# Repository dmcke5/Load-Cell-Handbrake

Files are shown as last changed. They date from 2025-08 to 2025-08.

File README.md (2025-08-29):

# CNCDan - Load Cell Handbrake
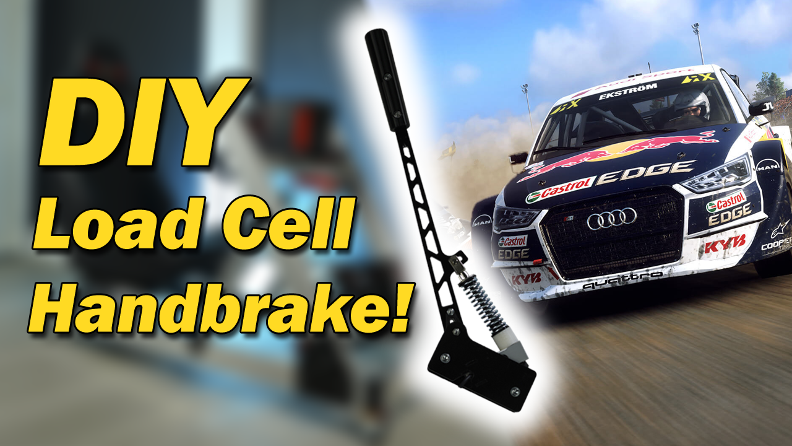
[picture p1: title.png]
Load Cell Handbrake


A load cell based handbrake design that's compatible with all of my other DIY Sim Racing projects.

[Project Video Link](https://youtu.be/xzpE0UGo8F0)

There are two different versions of the handbrake design, "Printed" and "Laser cut".
The laser cut version does still have some printed components, but the printed version does not require any laser cut parts!

Both versions are based around the same NA151 200kg Load cell - https://www.aliexpress.com/item/1005005510555008.html

And the INA333 amplifier board - https://www.aliexpress.com/item/1005007130064459.html

The files are split up into folders for each version. I've supplied STEP files for the parts that need to be laser cut, and STL files for any of the printed components! Each file has an x number at the end to denote how many copies of that part need to be made.

The "TPE Brake Bushing" file should be printed in flexible filament and without external walls to allow the print to compress nicely. I printed mine at 75% infill but you can tune that number up and down to vary the hardness.

Code to support both versions of the handbrake is now included in the [H-Shifter](https://github.com/dmcke5/H-Shifter) software. If you don't already have the shifter, this code can still be used without any modifications. Here is a wiring diagram to connect the Load cell to the INA333 board and then your Arduino. Make sure you include the jumpers across the potentiometer and between VREF and GND:

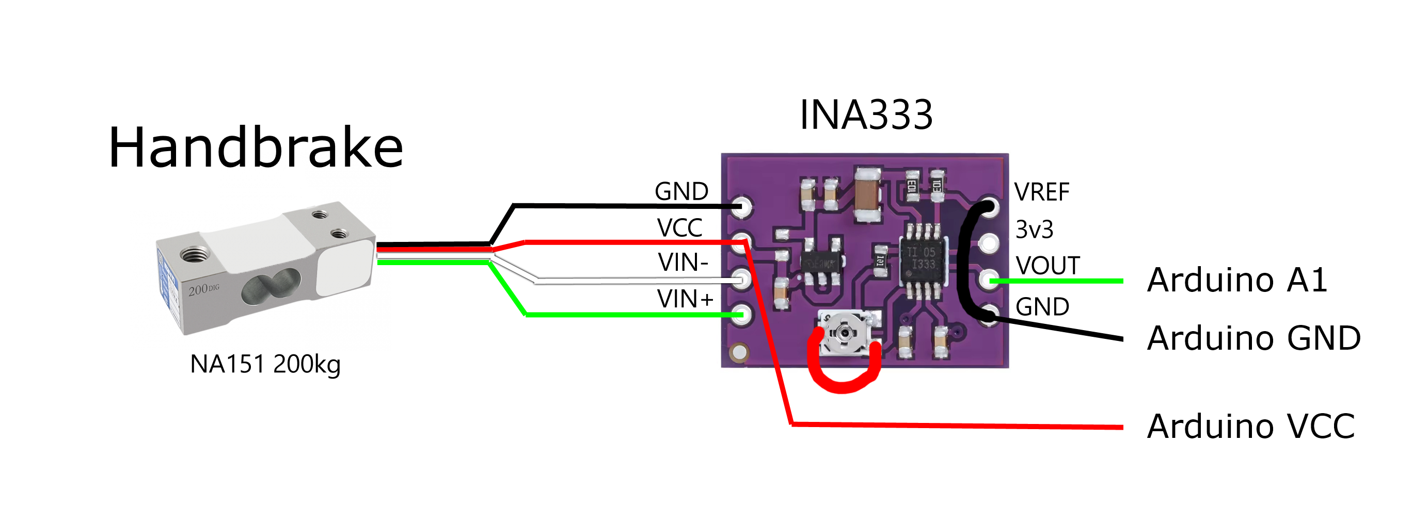
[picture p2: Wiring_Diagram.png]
Wiring Diagram


You'll also need the following items:

1x M6 Clevis - https://www.aliexpress.com/item/1005001383989512.html

1x M6x25 Washer - https://www.aliexpress.com/item/1005008724152831.html

22mm Diameter 70mm Long 3mm Wire Spring - https://www.aliexpress.com/item/1005007839215181.html

1x M6x140mm - https://www.aliexpress.com/item/1005008952546224.html

2x 625 Bearings - https://www.aliexpress.com/item/1005006600483688.html

1x 6x12x8 Retaining Collar - https://www.aliexpress.com/item/1005004975920947.html

3x M5x50 (45's would be acceptable for the Laser cut version) - https://www.aliexpress.com/item/32965712827.html

3x M5 Nyloc Nut - https://www.aliexpress.com/item/1005008280044118.html

#### Extra parts for Laser Cut Version Only

2x M6 Nyloc Nut - https://www.aliexpress.com/item/1005008280044118.html

2x M6x20 - https://www.aliexpress.com/item/32965712827.html

2x M5x35 - https://www.aliexpress.com/item/32965712827.html

#### Extra parts for Printed Version Only

2x M5x60 - https://www.aliexpress.com/item/32965712827.html

1x 10mm Shaft 350mm Long - https://www.aliexpress.com/item/1005006293171727.html

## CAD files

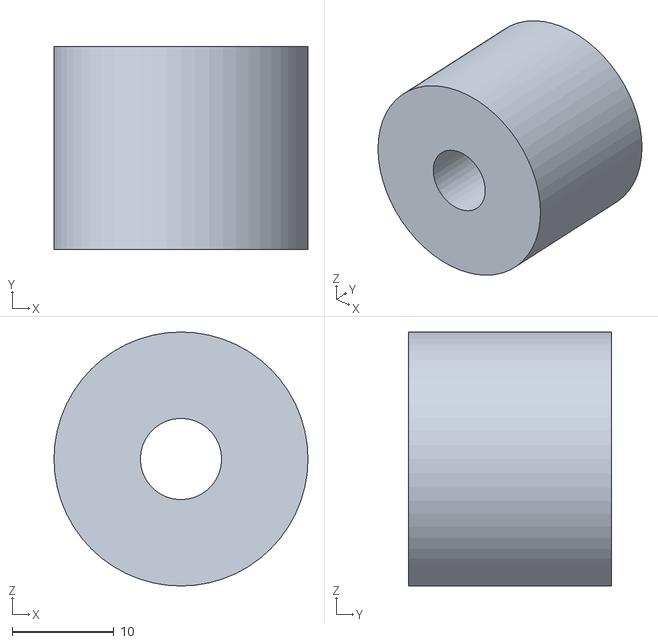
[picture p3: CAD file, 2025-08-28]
3D Files/Laser Cut Version/TPE Brake Bushing x1.STL
25.0 x 20.0 x 25.0

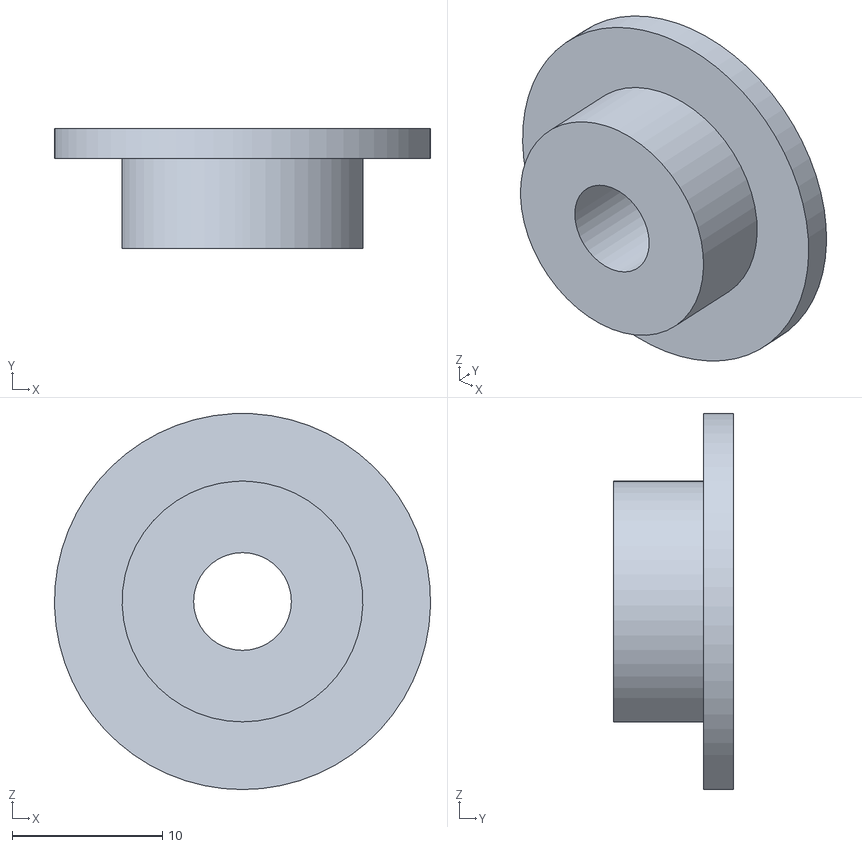
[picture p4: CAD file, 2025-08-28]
3D Files/Laser Cut Version/Spring Seat x2.STL
25.0 x 8.00 x 25.0

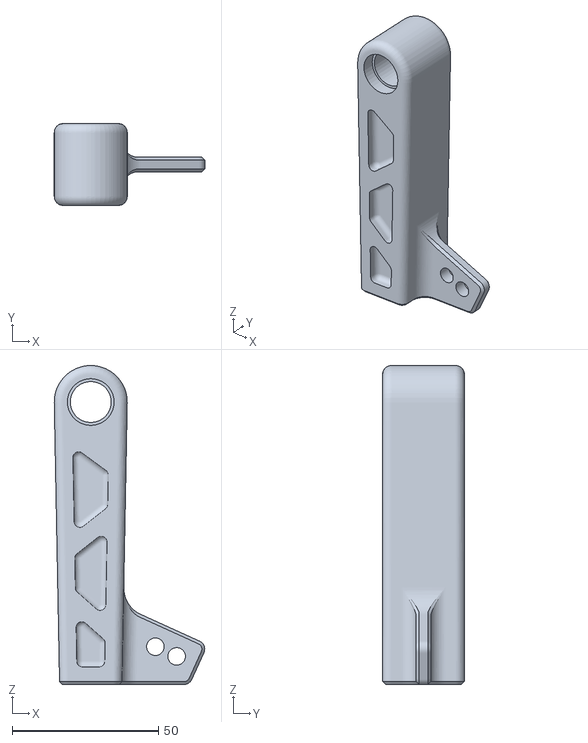
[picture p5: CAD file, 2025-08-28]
3D Files/Printed Version/Printed - Handbrake Arm Base x1.STL
51.5 x 28.0 x 109.2

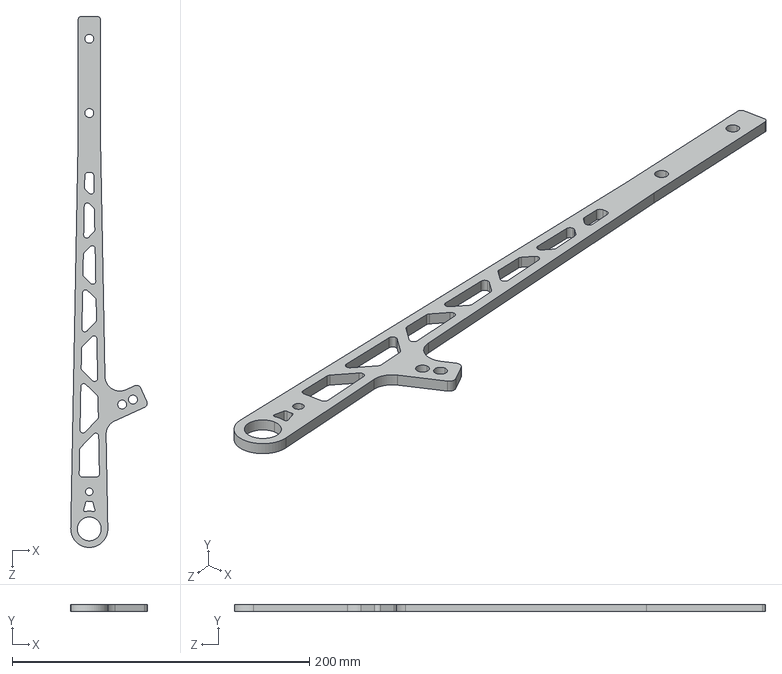
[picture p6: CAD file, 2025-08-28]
3D Files/Laser Cut Version/Laser - Handbrake Arm x1.STEP
51.5 x 5.00 x 357.5 mm

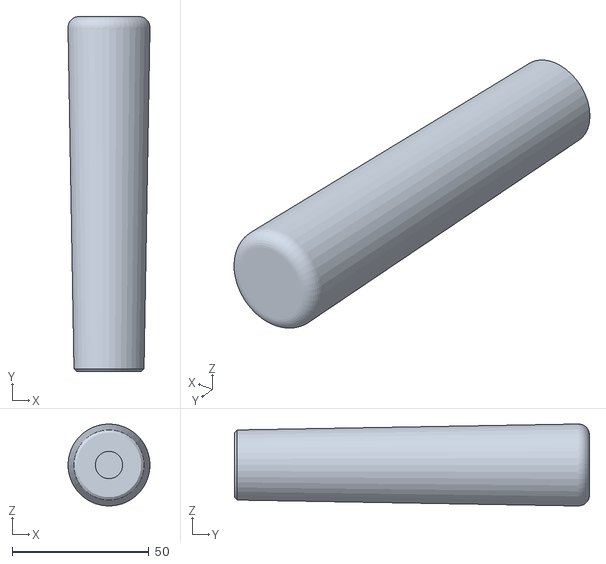
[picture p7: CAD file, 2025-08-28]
3D Files/Printed Version/Printed - Handbrake Arm Handle x1.STL
30.0 x 130.0 x 30.0

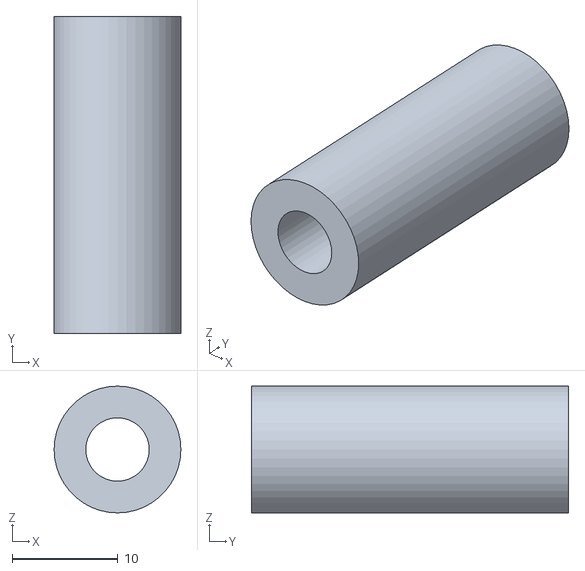
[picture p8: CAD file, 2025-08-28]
3D Files/Laser Cut Version/Laser - Handbrake Plate Spacer x2.STL
12.0 x 30.0 x 12.0

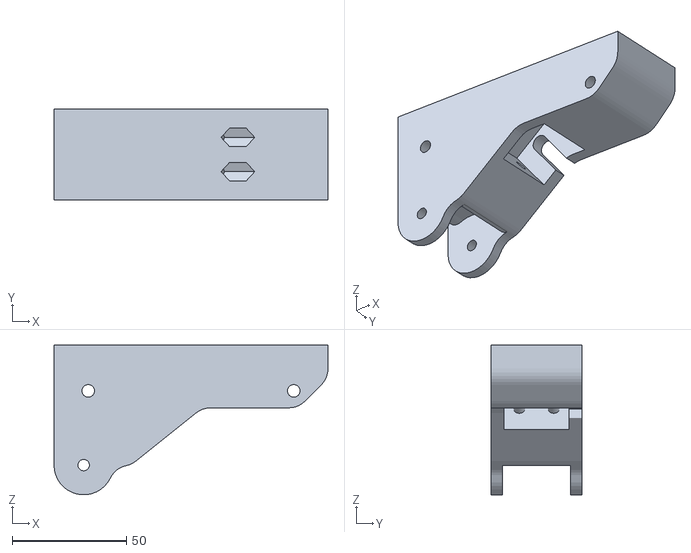
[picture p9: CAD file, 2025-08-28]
3D Files/Printed Version/Printed - Handbrake Base x1.STL
120.0 x 40.0 x 65.5

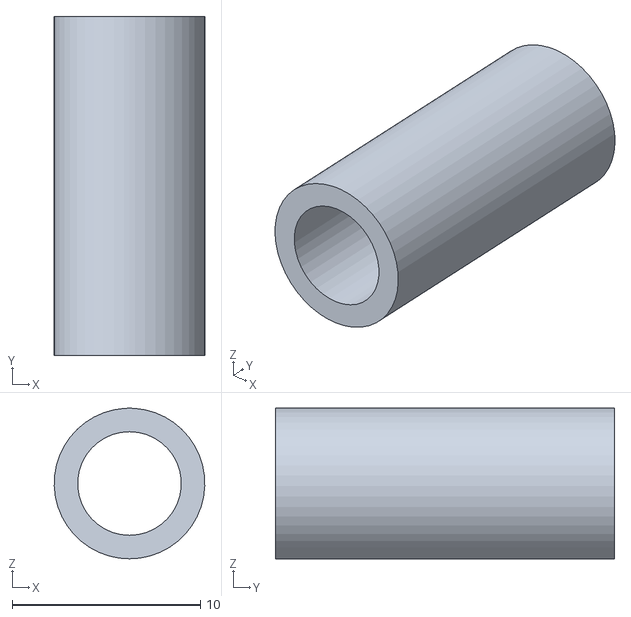
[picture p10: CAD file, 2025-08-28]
3D Files/Laser Cut Version/Handbrake Bearing Crush Tube x1.STL
8.00 x 18.0 x 8.00

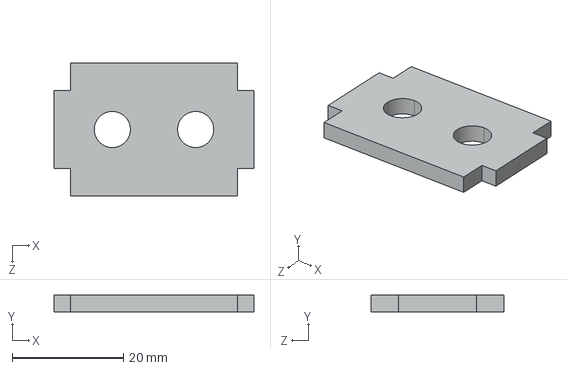
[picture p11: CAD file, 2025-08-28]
3D Files/Laser Cut Version/Laser - Handbrake Load Cell Bracket x2.STEP
36.0 x 3.00 x 24.0 mm

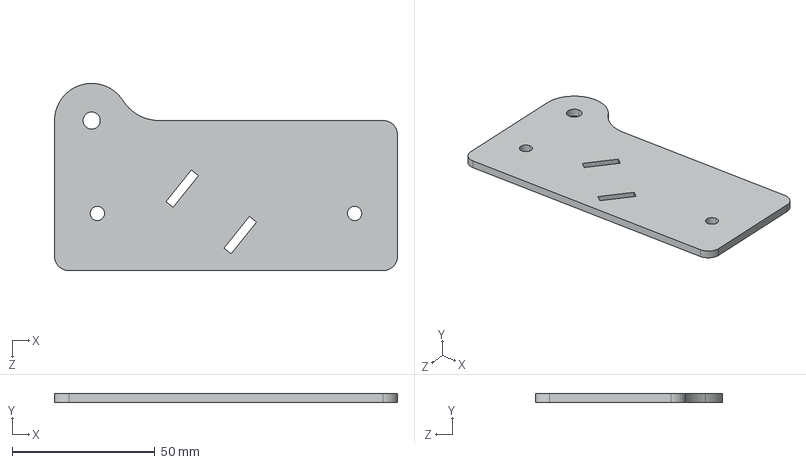
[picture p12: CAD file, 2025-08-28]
3D Files/Laser Cut Version/Laser - Handbrake Side Plate 2 x1.STEP
120.0 x 3.00 x 65.5 mm

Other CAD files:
3D Files/Laser Cut Version/Laser - Handbrake Side Plate 1 x1.STEP

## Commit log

2025-08-28 Add 3d Files
    [Handbrake Bearing Crush Tube x1.STL, Laser - Handbrake Arm x1.STEP, Laser - Handbrake Load Cell Bracket x2.STEP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]
2025-08-28 Update Readme/Added files
    [TPE Brake Bushing x1.STL]
2025-08-28 Add wiring Diagram
2025-08-28 Add BOM
